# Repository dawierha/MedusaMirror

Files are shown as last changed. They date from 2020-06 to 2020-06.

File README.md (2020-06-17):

# Mirror PI - The mirror that's avoiding you

Run main code:

```
python3 faceReg.py
```
Test the functionality of the motors
```
python3 steer_motor.py -m 0 -d 0 -s 30
```

## Dependencies
Basic dependencies for Opencv
```
sudo apt-get install build-essential cmake pkg-config
sudo apt-get install libjpeg-dev libtiff5-dev libjasper-dev libpng-dev
sudo apt-get install libavcodec-dev libavformat-dev libswscale-dev libv4l-dev
sudo apt-get install libfontconfig1-dev libcairo2-dev
sudo apt-get install libgdk-pixbuf2.0-dev libpango1.0-dev
sudo apt-get install libgtk2.0-dev libgtk-3-dev
sudo apt-get install libhdf5-dev libhdf5-serial-dev libhdf5-103
sudo apt-get install libqtgui4 libqtwebkit4 libqt4-test python3-pyqt5
sudo apt-get install python3-dev
```

Optimization libraries
```
sudo apt-get install libatlas-base-dev gfortran
```

Install opencv via pip 
```
sudo pip3 install opencv-contrib-python
```

These steps are a summary from this opencv installation [guide](https://www.pyimagesearch.com/2019/09/16/install-opencv-4-on-raspberry-pi-4-and-raspbian-buster/)

### Troubleshooting
* If you get this error ```undefined symbol: __atomic_fetch_add_8```  
    Run this command: ``` export LD_PRELOAD='/usr/lib/arm-linux-gnueabihf/libatomic.so.1' ``` 
    Or source the .env file included ``` source .env ```

## Camera
In order to activate the camera on the RPI, follow this [guide.](https://www.raspberrypi.org/documentation/configuration/camera.md)

Camera settings from [opencv.](https://stackoverflow.com/questions/11420748/setting-camera-parameters-in-opencv-python)

Camera settings for the raspberry built in programs [programs.](https://www.raspberrypi.org/documentation/raspbian/applications/camera.md)

https://www.pyimagesearch.com/2015/03/30/accessing-the-raspberry-pi-camera-with-opencv-and-python/

https://picamera.readthedocs.io/en/release-1.13/

Running a preview of the camera with the built-in Raspberry pi programs:

```raspivid -p 0,0,640,480 -t 0  ```

Best possible light through mirror I could find for now:

``` raspivid -p 0,0,640,480 -t 0 -fps 5 -ex night```

## GPIO
A summary of the GPIO library used can be found [here.](https://www.ics.com/blog/control-raspberry-pi-gpio-pins-python)
### Pinout map
Pinout map of the Raspberry Pi
```
   3V3  (1) (2)  5V    
 GPIO2  (3) (4)  5V    
 GPIO3  (5) (6)  GND   
 GPIO4  (7) (8)  GPIO14
   GND  (9) (10) GPIO15
GPIO17 (11) (12) GPIO18
GPIO27 (13) (14) GND   
GPIO22 (15) (16) GPIO23
   3V3 (17) (18) GPIO24
GPIO10 (19) (20) GND   
 GPIO9 (21) (22) GPIO25
GPIO11 (23) (24) GPIO8 
   GND (25) (26) GPIO7 
 GPIO0 (27) (28) GPIO1 
 GPIO5 (29) (30) GND   
 GPIO6 (31) (32) GPIO12
GPIO13 (33) (34) GND   
GPIO19 (35) (36) GPIO16
GPIO26 (37) (38) GPIO20
   GND (39) (40) GPIO21
```

### Connections
Table with the connections for the motors and switches
| Name          | Pin number | Color |
| ------------- |:----------:| -----:|
| direction  m1 |   3 	     | Green |
| step       m1 |   5  	     | Yellow|
| enable     m1 |   7 	     | White |
| switch_gnd m1 |   9        | Brown |
| switch     m1 |   11       | White |
| direction  m2 |   8        | Green |
| step       m2 |   10       | Yellow|
| enable     m2 |   12       | White |
| switch_gnd m2 |   14       | Brown |
| switch     m2 |   16       | White |

## TODO
* Two callback functions
* Handle what happens when the function reaches the endpoints
* Set appropiate max angle on motors

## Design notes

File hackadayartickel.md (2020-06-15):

Lite tankar om vad som vi kan ha med i vår artickel

Video/gif med spegel där någon försöker använda den för att raka eller sminka sig

Video/gif "innefrån" spegel, alltså vad spegeln ser, en ruta runte ett ansikte

länk till en github med alla delar, kod, stl, BOM

caveats, typ vår konding samt varför vi använder den

Supersnygga bilder på spegeln och kanske till och med oss

vad vi ska lägga till på den i framtiden

https://hackaday.com/submit-a-tip/
https://hackaday.com/2018/05/01/the-anxiety-of-open-source-why-we-struggle-with-putting-it-out-there

A short video demonstrating the project.

A photo gallery, ideally with captions, and ideally with some glamour shots at different aspect ratios (a wide shot, a square shot, and a tall shot).

A writeup that includes the backstory, design considerations, build process, and results, with ideally some snippets about interesting problems encountered or clever solutions, or in general things that are noteworthy and unique. This should not be too long.

Links to appropriate repositories/files/libraries.

A license (makes it known how your work and be reused without the need to contact you first)

all caveats, så som kondingen från switchen
faild 3D prints now as mugg holder an pen holder

Base plate in Lund w. brother getting car fetured in other project

block diagram

# titel
Rude mirror does not wanna look at you
Mirror thinks you are too ugly to look at
This mirror thinks you are too ugly
Makeup artists hate this mirror, and here's why

# Project summerisation
This unconvential mirror turns away from you when you loo into it. A mirror that form the look of it does not have any electronics moves away when used.

# Images
på spegeln
på block diagram av komponenter
stegmotordrivare
inuti botten cylinder
cad model

# Description
Face recognigtion 
camera bakom spegeln, exponereing i kameran
två motorer en uppe en nere
konding på swtich
open cv
långsam kör i två processorer

# Externa links
youtube
github
min blogg

# TODO
## Erik
Film
Description

## Daniel
Github och github page
bilder
block diagram
Börja på en BOM

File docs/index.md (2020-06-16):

# Description

this is the description part

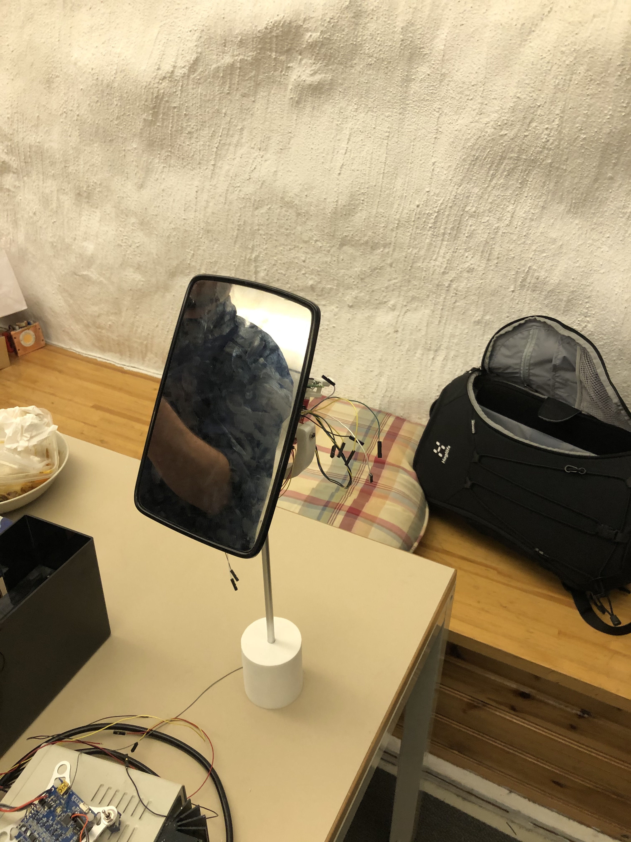
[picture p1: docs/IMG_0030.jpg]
Test image


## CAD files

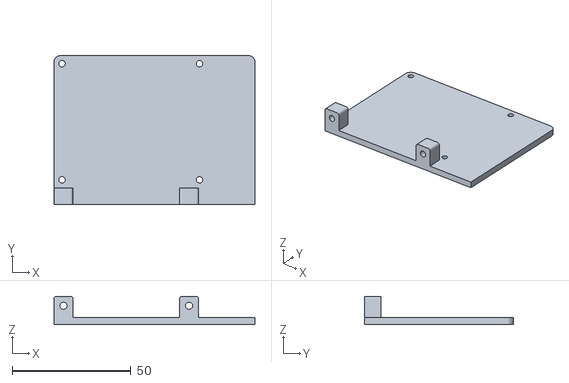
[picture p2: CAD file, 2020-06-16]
partsToPrint/rpiholder.stl
84.8 x 63.0 x 12.0

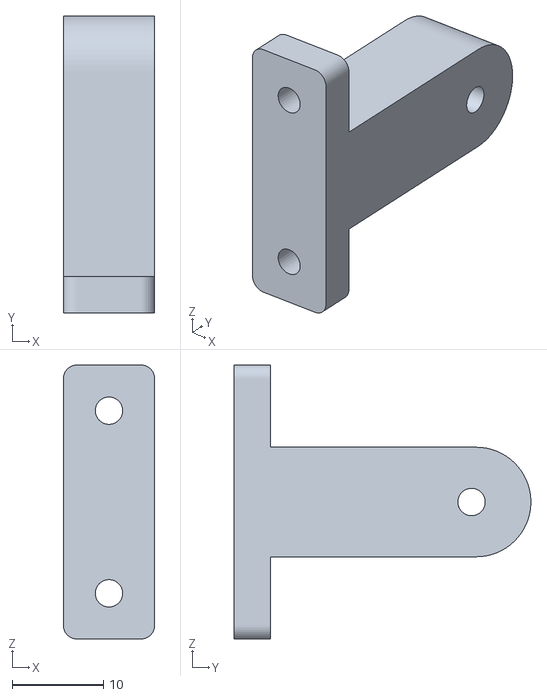
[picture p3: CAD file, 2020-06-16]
partsToPrint/jointattach.stl
10.0 x 32.5 x 30.0

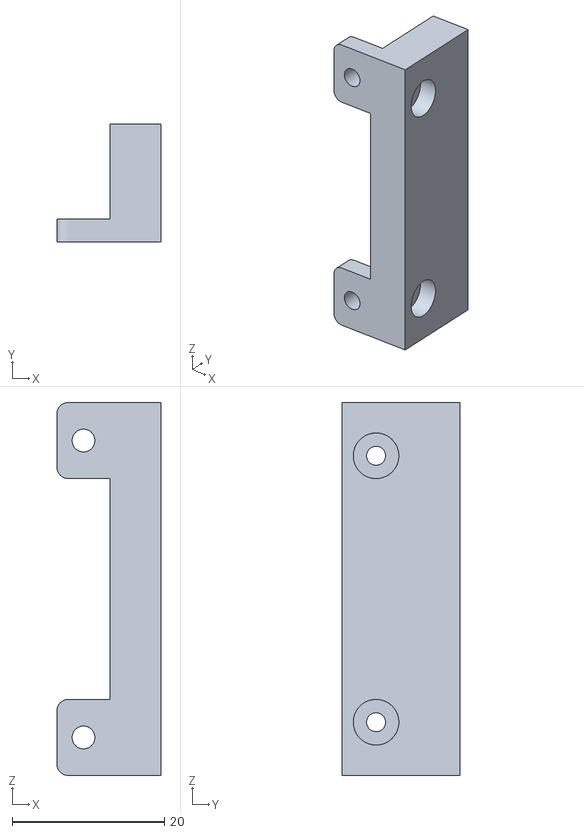
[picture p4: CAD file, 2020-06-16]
partsToPrint/motordriverholder.stl
13.7 x 15.4 x 49.0

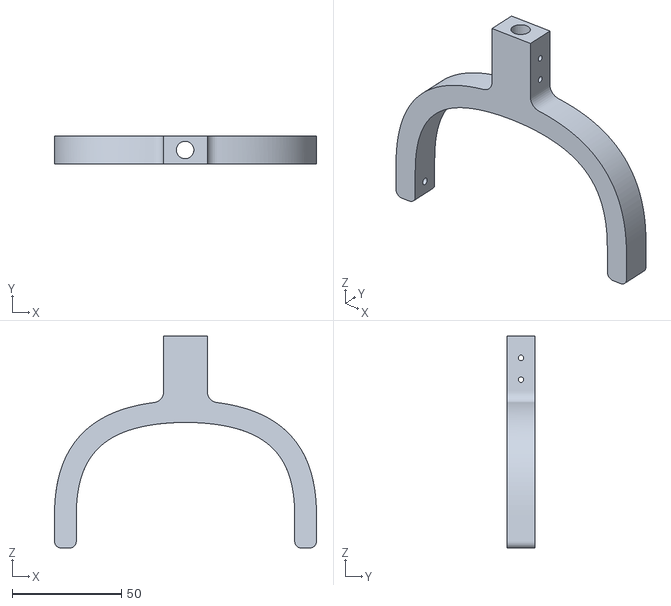
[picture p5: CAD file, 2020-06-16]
partsToPrint/fork.stl
120.0 x 13.0 x 97.1

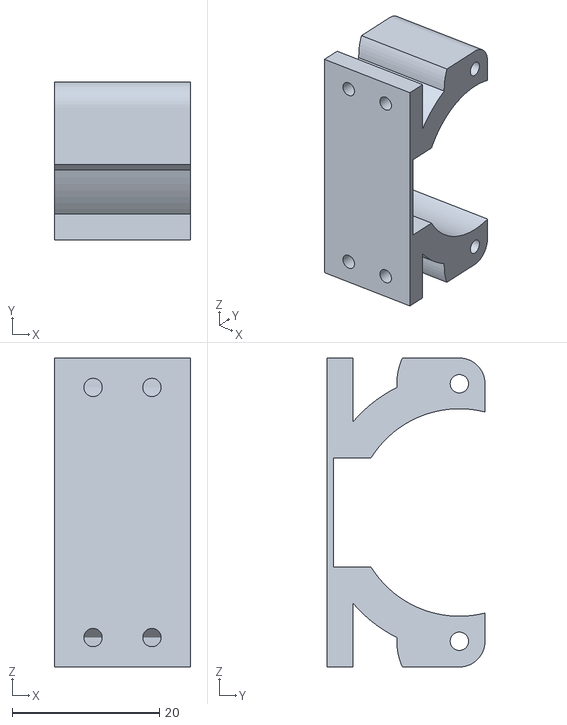
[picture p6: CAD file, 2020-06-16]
partsToPrint/topmotorholder.stl
18.5 x 21.5 x 42.0

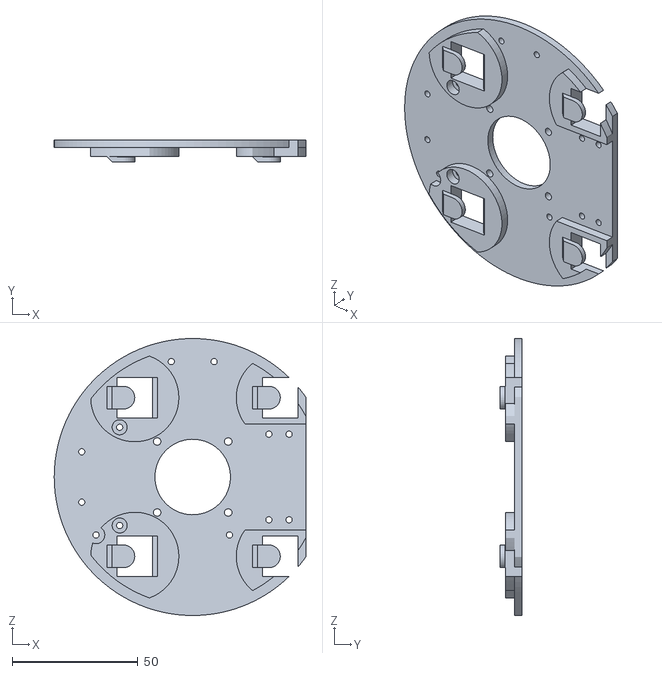
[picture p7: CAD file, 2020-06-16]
partsToPrint/mirroradapter.stl
99.9 x 8.60 x 110.0

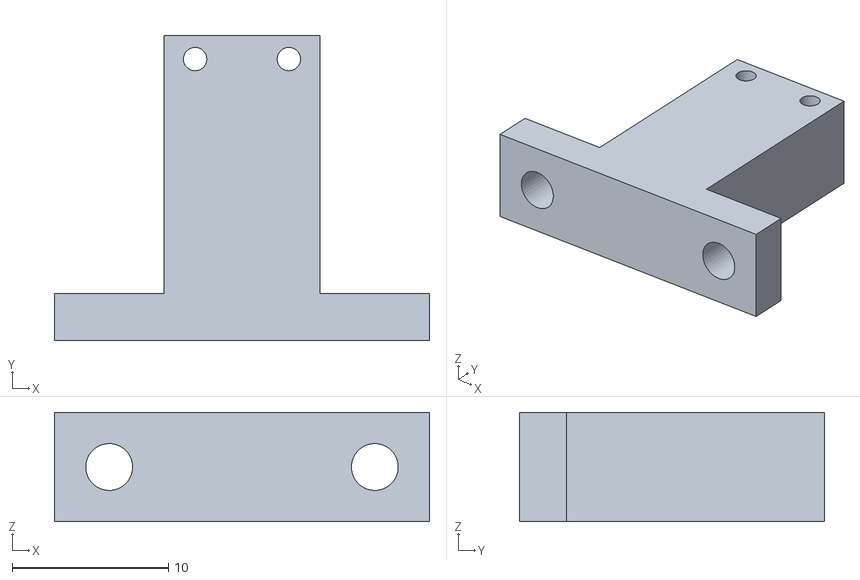
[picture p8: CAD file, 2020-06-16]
partsToPrint/endstopswtichholder.stl
24.0 x 19.5 x 7.00

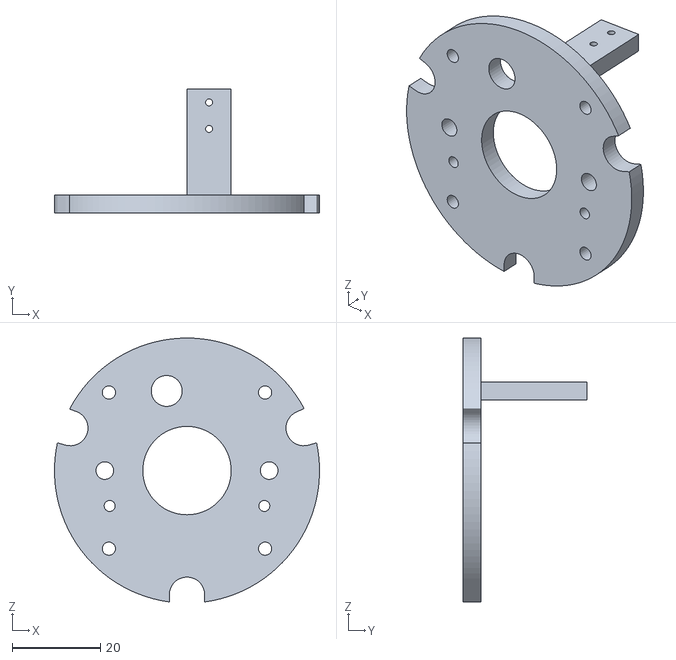
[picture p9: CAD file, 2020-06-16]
partsToPrint/basemotorholder.stl
60.0 x 28.0 x 59.7

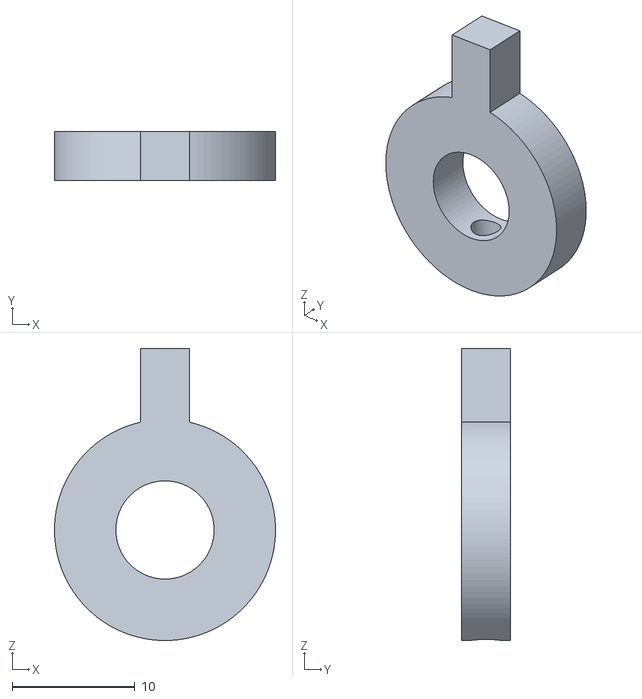
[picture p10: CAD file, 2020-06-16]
partsToPrint/endstoplever.stl
18.0 x 4.00 x 23.8

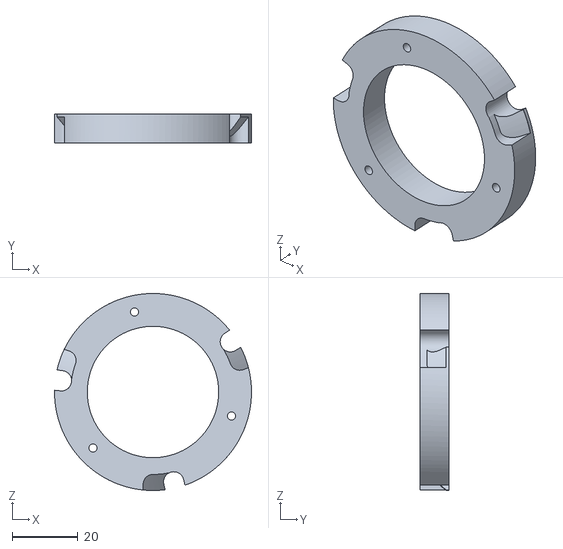
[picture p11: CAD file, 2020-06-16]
partsToPrint/basplateadapter.stl
60.0 x 8.90 x 60.0

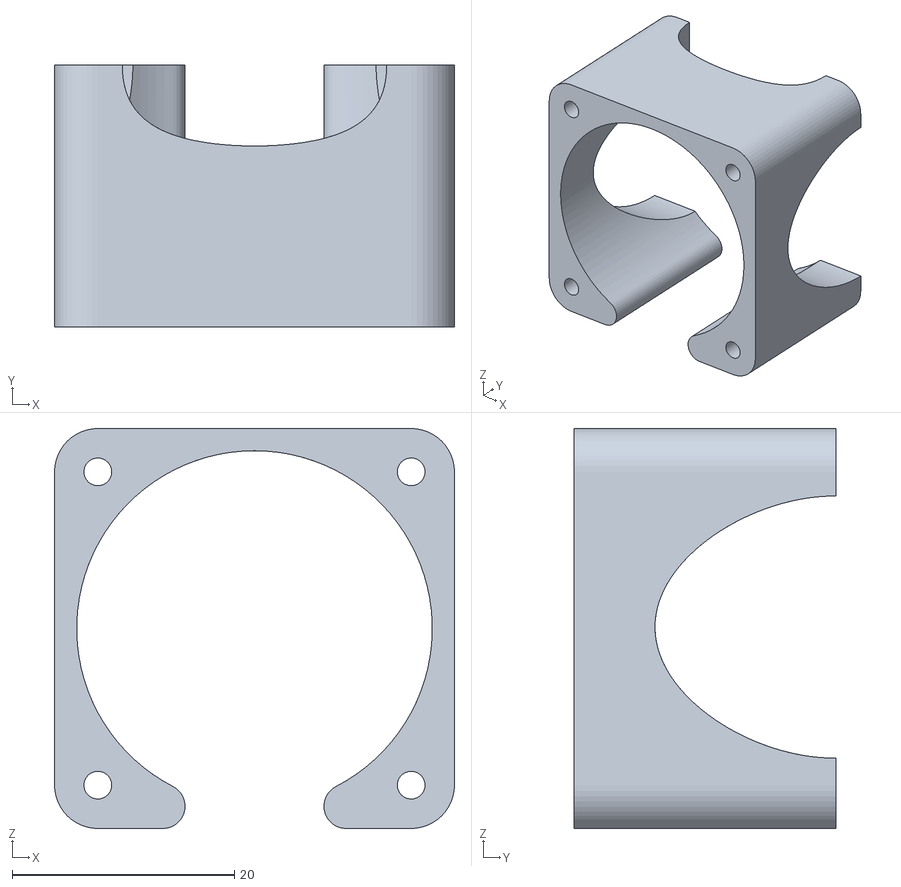
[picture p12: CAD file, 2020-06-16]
partsToPrint/cameraHolder.stl
36.0 x 23.6 x 36.0

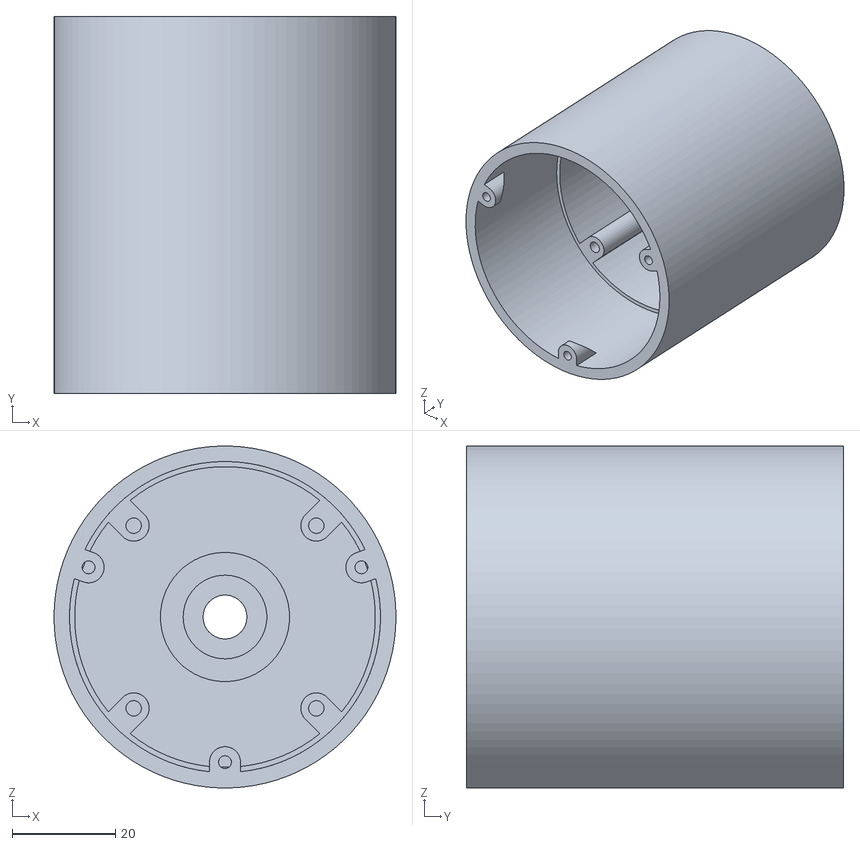
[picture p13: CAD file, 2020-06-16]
partsToPrint/basecylinder.stl
66.2 x 73.0 x 66.2

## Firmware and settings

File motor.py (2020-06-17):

import RPi.GPIO as GPIO
import time
import argparse
import sys
import atexit

class Motor():
    def __init__(self, motor_id, direction_pin, step_pin, enable_pin, switch_pin, 
                 max_angle, rewind_angle, debug=False):
        self.motor_id = motor_id
        self.direction_pin = direction_pin
        self.step_pin = step_pin
        self.enable_pin = enable_pin
        self.switch_pin = switch_pin
        self.max_angle = max_angle
        self.rewind_angle = rewind_angle
        self.angle = 0
        self.cc_dirr = GPIO.LOW     #Counter clockwise direction
        self.cw_dirr = GPIO.HIGH    #Clockwise direction
        self.debug = debug

        GPIO.setup(enable_pin, GPIO.OUT)
        GPIO.setup(step_pin, GPIO.OUT)
        GPIO.setup(direction_pin, GPIO.OUT)
        GPIO.setup(switch_pin, GPIO.IN, pull_up_down=GPIO.PUD_UP)

        self.disable()

    #Turns on motor
    def enable(self): 
        GPIO.output(self.enable_pin, GPIO.LOW)

    #Turns off motor
    def disable(self): 
        GPIO.output(self.enable_pin, GPIO.HIGH)

    def add_event_detect(self, edge=GPIO.FALLING, bouncetime=600):
        GPIO.add_event_detect(self.switch_pin, edge, callback=self.cb_switch, bouncetime=bouncetime)

    def cb_switch(self, channel):
        if self.debug: print(f"Entered callback for motor {self.motor_id}")
        self.disable()
        
    def take_step(self, timeout):
        GPIO.output(self.step_pin, GPIO.LOW)
        GPIO.output(self.step_pin, GPIO.HIGH)
        time.sleep(timeout)

    def calibrate(self):
        if self.debug: print(f"Calibrating Motor {self.motor_id}")
        GPIO.output(self.enable_pin, GPIO.LOW)
        GPIO.output(self.direction_pin, self.cc_dirr)
        steps=0
        while GPIO.input(self.switch_pin):
            self.take_step(0.008)
            if self.debug: sys.stdout.write(f"\rMotor {self.motor_id} Steps: {steps}")
            sys.stdout.flush()
            steps += 1
        if self.debug: print("")
        self.angle = 0
        GPIO.output(self.direction_pin, self.cw_dirr)
        while self.angle <= self.rewind_angle:
            self.take_step(0.008)
            self.angle += 1
        if self.debug: print(f"Calibration done for motor {self.motor_id}")

    def edge_handling(self, direction, target_angle, timeout):
        if self.debug: print(f"Entered Edgehandling for motor {self.motor_id} with angle: {self.angle}")
        self.enable()
        GPIO.output(self.direction_pin, direction)
        while direction*(self.angle <= target_angle) or (direction^1)*(self.angle >= target_angle):
            self.take_step(timeout)
            self.angle += direction*2-1
            if self.debug: sys.stdout.write(f"\rEdge Motor {self.motor_id} Angle: {self.angle}")
        if self.debug: print("")
    
    #Moves one step in the given 'direction'. Checks that the angle is witin bounds
    def move(self, direction, timeout):
        if self.angle < self.max_angle and GPIO.input(self.switch_pin):
            GPIO.output(self.direction_pin, direction)
            self.take_step(timeout)      
            self.angle += direction*2-1   
        
        elif self.angle >= self.max_angle:
            self.edge_handling(self.cc_dirr, int(self.max_angle/2), timeout)  
        
        elif not GPIO.input(self.switch_pin):
            time.sleep(0.05)
            self.angle = 0 
            self.edge_handling(self.cw_dirr, int(self.max_angle/2), timeout)

    #Moves 'angle' decidegrees in the given 'direction'. Checks that the angle is whitin bounds
    def move_angle(self, direction, angle, timeout):
        target_angle = self.angle + (direction*2-1)*angle
        GPIO.output(self.direction_pin, direction)
        while direction*(self.angle <= target_angle) or (direction^1)*(self.angle >= target_angle):
            if self.angle >= self.max_angle or self.angle < 0 or GPIO.event_detected(self.switch_pin):
                if self.debug: print(f"\nMotor {self.motor_id}, Angle out of bounds. Angle: {self.angle}")
                if self.angle >= self.max_angle:
                    self.edge_handling(self.cc_dirr, int(self.max_angle/2), 0.0008)
                elif not GPIO.input(self.switch_pin):
                    self.angle = 0  
                    self.edge_handling(self.cw_dirr, int(self.max_angle/2), 0.0008)
                sys.stdout.flush()
                break
            self.take_step(timeout)
            self.angle += direction*2-1
            if self.debug>1: sys.stdout.write(f"\rMotor {self.motor_id} Angle: {self.angle}")
            sys.stdout.flush()
        if self.debug>1: print("")
        sys.stdout.flush()

def cleanup():
    GPIO.cleanup()

if __name__ == "__main__":
    #Arguemnts parsing
    parser = argparse.ArgumentParser(description="Motor controll")
    parser.add_argument("-m","--motor", help="Select which motor to be turned. Can be either 0, 1, 2. Default 1. 0 selects both motors", 
                        type=int, choices=[0, 1, 2], default=1)
    parser.add_argument("-d","--direction", help="Selects which direction to turn the motor. Can be eitehr 0 or 1. Default 0.", 
                        type=int, choices=[0, 1], default=0)
    parser.add_argument("-s","--steps", help="Specifies the number of steps the motor should take. Default 30.", type=int,
                        default=30)             
    args = parser.parse_args()
    print(f"Motor: {args.motor}, direction: {args.direction}, steps: {args.steps}")

    atexit.register(cleanup)

    #Pin setup
    direction_1 = 3 	#Green
    step_1 = 5  	    #Yellow
    enable_1 =7 	    #White
    switch_1 = 11       #White
    direction_2 = 8 	#Green
    step_2 = 10  	    #Yellow
    enable_2 = 12 	    #White
    switch_2 = 16       #White

    GPIO.setmode(GPIO.BOARD)
    GPIO.setwarnings(False)
    
    if args.motor == 1 or args.motor == 0:
        motor_1 = Motor(1, direction_1, step_1, enable_1, switch_1, 500, 250, debug=True)
        motor_1.move_angle(args.direction, args.steps, 0.016)
    if args.motor == 2 or args.motor == 0:
        motor_2 = Motor(2, direction_2, step_2, enable_2, switch_2, 1000, 150, debug=True)
        motor_2.move_angle(args.direction, args.steps, 0.016)
    while True:
        pass

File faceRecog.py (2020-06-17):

import cv2
import atexit
import numpy as np
import argparse
import RPi.GPIO as GPIO
import time
import sys
import signal
from picamera import PiCamera, mmal
from picamera.array import PiRGBArray
from picamera.mmalobj import to_rational
from multiprocessing import Process, Queue, Event
from motor import Motor

MAX_ANGLE_1 = 1500
MAX_ANGLE_2 = 900
REWIND_ANGLE_1 = 750 #Rewind angle for motor 1
REWIND_ANGLE_2 = 150   #Rewind angle for motor 2

def cleanup():
    GPIO.cleanup()

def motorThread(stop_event, calibrate_event, in_q, en_g):
    signal.signal(signal.SIGINT, signal.SIG_IGN)
    motor_1 = Motor(1, direction_1, step_1, enable_1, switch_1, MAX_ANGLE_1, REWIND_ANGLE_1, debug=debug)
    motor_2 = Motor(2, direction_2, step_2, enable_2, switch_2, MAX_ANGLE_2, REWIND_ANGLE_2, debug=debug)
    motor_1.calibrate()
    motor_2.calibrate()
    
    motor_1.add_event_detect()
    motor_2.add_event_detect()
    
    calibrate_event.set()   #Tells the camThread that the motors are ready
    direction = None
    enable = None
    while True:
        #Shuts the thread off
        if stop_event.is_set():
            break

        if in_q.qsize() > 0:
            direction = in_q.get()
        if en_q.qsize() > 0:
            enable = en_q.get()
        if enable:
            motor_1.move(direction, 0.0008)
        

def camThread(stop_event, calibrate_event, out_q, en_q):
    signal.signal(signal.SIGINT, signal.SIG_IGN)
    # Load the cascade
    face_cascade = cv2.CascadeClassifier('haarcascade_frontalface_default.xml')
    if debug: print("\nLoaded cascade")    
    #Sets up the camera
    with PiCamera() as camera:
        camera.resolution = (640, 480)
        camera.framerate = 5
        camera.exposure_mode = 'night'
        #Sets digital gain to 8.0
        mmal.mmal_port_parameter_set_rational(camera._camera.control._port, mmal.MMAL_PARAMETER_GROUP_CAMERA + 0x5A, to_rational(8.0))
        rawCapture = PiRGBArray(camera, size=(640, 480))
        
        width = camera.resolution[0]
        time_stamp_old = time.perf_counter() 
        calibrate_event.wait() #Waits for the motor to finnish calibrating
        for frame in camera.capture_continuous(rawCapture, format="bgr", use_video_port=True):
            #print(f"target fps: {camera.framerate}, dg: {camera.digital_gain}, exposure: {camera.exposure_mode}")
            # Read the frame
            img = frame.array

            # Convert to grayscale
            gray = cv2.cvtColor(img, cv2.COLOR_BGR2GRAY)
            
            # Detect the faces
            faces = face_cascade.detectMultiScale(gray, 1.1, 4)
            
            # Draw the rectangle around each face and detects decides if it wants to go left or right
            enable = False
            for (x, y, w, h) in faces:
                enable = True
                if args.show:
                    cv2.rectangle(img, (x, y), (x+w, y+h), (255, 0, 0), 2)
                center = (x+w/2, y+h/2)
                if center[0] <= width/2:
                    if debug: print("Left half of image")
                    out_q.put(GPIO.HIGH)
                else:
                    if debug: print("Right half of image")
                    out_q.put(GPIO.LOW)
            en_q.put(enable)
            
            # Display
            if args.show:
                cv2.imshow('img', img)
            # Stop if escape key is pressed
            k = cv2.waitKey(30) & 0xff
            if k==27:
                break
            
            # clear the stream in preparation for the next frame    
            rawCapture.truncate(0)
            rawCapture.seek(0)
            
            #Calculates and prints the FPS to std out
            if args.fps:
                time_stamp_new = time.perf_counter() 
                fps = 1/(time_stamp_new-time_stamp_old)
                sys.stdout.write("\rFPS: {0} ".format(round(fps, 1)))
                sys.stdout.flush()
                time_stamp_old = time_stamp_new

            #shuts the thread off
            if stop_event.is_set():
                break

if __name__ == "__main__":
    #Arguemnts parsing
    parser = argparse.ArgumentParser(description="Mirror Pi - The mirror that\'s avoiding you")
    parser.add_argument("-s","--show", help="Shows the camera and face recognition output to the screen", action="store_true")
    parser.add_argument("-c","--nocalibrate", help="Skips the calibration of the motors", action="store_true")
    parser.add_argument("-f","--fps", help="Calculates and prints the FPS to std out", action="store_true")
    parser.add_argument("-d", "--debug", help="Prints debug statements to std out", action="count", default=0)
    args = parser.parse_args()

    #This function is called when the program is forced to close
    atexit.register(cleanup)

    #Pin setup
    direction_1 = 3 	#Green
    step_1 = 5  	    #Yellow
    enable_1 =7 	    #White
    switch_1 = 11       #White
    direction_2 = 8 	#Green
    step_2 = 10  	    #Yellow
    enable_2 = 12 	    #White
    switch_2 = 16       #White

    GPIO.setmode(GPIO.BOARD)
    GPIO.setwarnings(False)

    #Multiprocesses
    dir_q = Queue()
    en_q = Queue()
    stop_event = Event()
    calibrate_event = Event()
    debug = args.debug
    motor  = Process(target=motorThread, args=(stop_event, calibrate_event, dir_q, en_q,))
    camera = Process(target=camThread, args=(stop_event, calibrate_event, dir_q, en_q,))
    motor.start()
    camera.start()

    try:
        while True:
            pass
    except (KeyboardInterrupt, SystemExit):
        print("\nExiting...")
        stop_event.set()
        motor.join()
        camera.join()
        cleanup()

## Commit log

2020-04-12 stop face outside frame
2020-05-01 Endstop function added for init calibration
2020-05-01 calibration works
2020-05-02 Added input arguments and parsing for showing the camera input and skipping calibration
    [faceRecog.py]
2020-05-02 Added table with our pin connections for one of the motors
2020-05-04 Added references for adjusting camera parameters
2020-05-04 Added arguments for steer_motor
2020-05-04 added prettier output when printing num steps for calibration function
2020-05-10 Changed from opencvs camera library to piCamera in order to controll exposure time
2020-05-10 The threads are now safely exited when pressing ctrl+c
2020-05-11 Changed from threading to multiprocesses in order to utilize several cores
2020-05-14 Updataed pin number for motor two. Updated TODO
2020-06-02 Added functionality to steer the second motor
2020-06-02 Updated info for steer_motor.py
2020-06-02 Added second motor to faceRecog.py
2020-06-16 stl files added
    [basecylinder.stl, basemotorholder.stl, basplateadapter.stl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]
2020-06-17 Created motor class, and implemented __init__ and calibrate functions
2020-06-17 Implemented move_angel for motor
2020-06-17 Moved the test funcitions to motor.py
2020-06-17 callback function is now turning the motor back to half the max angle
2020-06-17 starting to remove motor logic
2020-06-17 Readded motorthread
2020-06-17 Fixed callback function issues
    [faceRecog.py, motor.py]
2020-06-17 Made the code faster but buggier
    [faceRecog.py]
2020-06-17 Moved the camthreads motor waiting point further down in the code
